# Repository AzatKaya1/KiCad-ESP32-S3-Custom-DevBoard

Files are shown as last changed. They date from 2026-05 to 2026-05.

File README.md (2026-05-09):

<div align="center">

# ⚡ ESP32-S3 Custom Development Board

</div>
<div align="center">

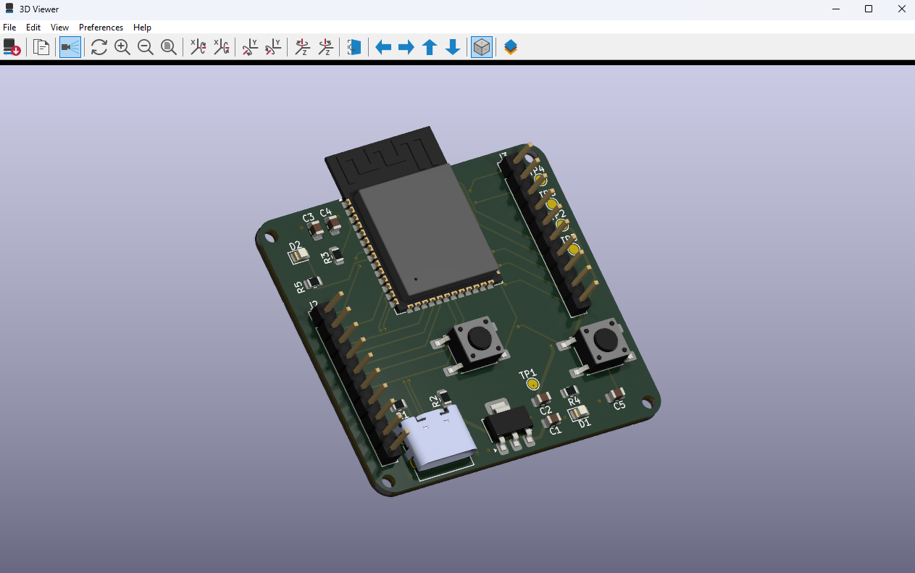
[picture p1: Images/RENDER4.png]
ESP32-S3 Custom DevBoard 3D Render


<br/>

**A production-grade, 4-layer PCB development board built around the ESP32-S3-WROOM-1 module.**  
Designed for signal integrity, RF performance, and professional-grade hardware standards.

<br/>



[]()

[]()

</div>

## 📋 Table of Contents

- [Overview](#-overview)
- [Key Features](#-key-features)
- [Technical Specifications](#-technical-specifications)
- [Advanced Hardware Design](#-advanced-hardware-design)
- [PCB Layer Stackup](#-pcb-layer-stackup)
- [Pinout & Peripherals](#-pinout--peripherals)
- [Repository Structure](#-repository-structure)
- [Manufacturing](#-manufacturing)

## 🔍 Overview

This project is an advanced, **production-ready development board** based on the **ESP32-S3-WROOM-1** module. It was designed with a focus on:

- ✅ **Signal Integrity** — Controlled impedance traces, optimized return paths
- ✅ **Power Stability** — Low-noise LDO regulation with proper decoupling
- ✅ **RF Performance** — Dedicated keep-out zone under the module antenna
- ✅ **Professional Standards** — 4-layer stackup, differential pair routing

This board is suitable for makers, engineers, and students who want a reliable ESP32-S3 platform for IoT, wireless communication, sensor integration, or embedded systems development.

## ✨ Key Features

| Feature | Detail |
|---|---|
| 🧠 MCU | ESP32-S3-WROOM-1 — Dual-core Xtensa LX7, Wi-Fi 4 & BLE 5.0 |
| ⚡ USB | Native USB-C for programming and power |
| 🔋 Power | 5V input → 3.3V via AMS1117-3.3 LDO |
| 📡 RF | Keep-out zone for optimized antenna performance |
| 📐 PCB | 4-layer stackup for reduced EMI |
| 🔌 Headers | UART, I2C, SPI — fully broken out |
| 📊 ADC | 2× dedicated analog input channels |
| 🔴 LEDs | Power LED (D1) + User-programmable LED (D2) |
| 🔘 Buttons | RESET (EN) + BOOT (GPIO0) |
| 🧪 Test Points | 5V, 3.3V, GND, TX, RX (TP1–TP5) |

## 🛠 Technical Specifications

| Parameter | Value |
|---|---|
| Microcontroller | ESP32-S3-WROOM-1 |
| CPU | Dual-core Xtensa LX7 @ up to 240 MHz |
| Wireless | Wi-Fi 802.11 b/g/n (2.4 GHz) + BLE 5.0 |
| Flash | Built-in (varies by module variant) |
| Input Voltage | 5V DC via USB-C |
| Operating Voltage | 3.3V (regulated via AMS1117-3.3) |
| PCB Layers | 4 (Signal / GND / Power / Signal) |
| PCB Tool | KiCad 9.0 |
| USB Interface | Native USB (D+/D- differential pair) |
| Programming | USB-C (native), UART via test points |

## 🔬 Advanced Hardware Design

### 1️⃣ 4-Layer PCB & Signal Integrity

The board uses a **4-layer stackup** to deliver superior electrical performance.

By using dedicated internal planes for **GND** and **3.3V**, electromagnetic interference (EMI) is significantly reduced, and power distribution is stabilized across the entire board.

### 2️⃣ Differential Pair Routing (USB D+/D-)

The USB-C data lines are routed as **90-ohm controlled impedance differential pairs**:

- Matched trace lengths for minimal skew
- Consistent spacing to maintain target impedance
- Prevents signal reflection and ensures error-free high-speed data transmission

### 3️⃣ RF Keep-Out Zone

A dedicated **RF Keep-Out Zone** is defined beneath the ESP32-S3-WROOM-1 antenna region:

- No copper, traces, or components on **any layer** in this region
- Maximizes Wi-Fi and Bluetooth range
- Minimizes signal attenuation and multipath interference

### 4️⃣ Power Design — AMS1117-3.3 LDO

The **AMS1117-3.3** was chosen for its:

- Low dropout voltage (~1.2V typical)
- 800mA output current capability
- Excellent noise performance for RF applications
- Wide availability and low cost for prototyping

> ⚠️ **Note:** For battery-powered or low-power designs, consider a more efficient LDO (e.g., MIC5219 or TPS7A20).

### 5️⃣ Decoupling & Bypass Capacitors

- 100nF ceramic capacitors placed close to each power pin of the ESP32-S3 module
- Bulk capacitance at the LDO output for transient response
- Ferrite bead filtering on power input

## 📐 PCB Layer Stackup

| Layer | Type | Description |
|---|---|---|
| Layer 1 (Top) | Signal | Components, USB, buttons, LEDs |
| Layer 2 | GND Plane | Solid ground pour — EMI shield & return path |
| Layer 3 | Power Plane | Solid 3.3V pour — stable power delivery |
| Layer 4 (Bottom) | Signal | Additional routing |

## 🔌 Pinout & Peripherals

| Header | Signals |
|---|---|
| UART | TX, RX, GND, 3.3V |
| I2C | SDA, SCL, GND, 3.3V |
| SPI | MOSI, MISO, SCK, CS, GND, 3.3V |
| ADC | ADC_CH1, ADC_CH2, GND |
| GPIO | Spare GPIO pins for custom expansion |
| Test Points | TP1 = 5V · TP2 = 3.3V · TP3 = GND · TP4 = TX · TP5 = RX |

## 📂 Repository Structure

| Folder / File | Description |
|---|---|
| `Hardware/` | KiCad 9.0 project files (`.kicad_pcb`, `.kicad_sch`, `.kicad_pro`) |
| `Manufacturing/` | Production-ready Gerber, Drill, and POS files |
| `Images/` | High-quality 3D renders |
| `.gitignore` | Git ignore rules |
| `LICENSE` | MIT License |
| `README.md` | This file |

## 🏭 Manufacturing

The `/Manufacturing` folder contains all files needed for PCB fabrication, compatible with major manufacturers:

| Service | Notes |
|---|---|
| [JLCPCB](https://jlcpcb.com) | Recommended — affordable 4-layer PCBs |
| [PCBWay](https://www.pcbway.com) | Good quality, various finish options |
| [OSH Park](https://oshpark.com) | US-based, ENIG finish standard |

**Recommended fab settings:**

| Parameter | Value |
|---|---|
| Layers | 4 |
| PCB Color | Black (recommended) |
| Surface Finish | HASL or ENIG |
| Board Thickness | 1.6mm |
| Copper Weight | 1oz outer / 0.5oz inner |
| Min Trace/Space | 0.15mm |
| Min Hole Size | 0.3mm |

---

<div align="center">

**Designed with  by [Azat KAYA](https://www.linkedin.com/in/azatkaya1/)**



*If this project helped you, consider giving it a ⭐ on GitHub!*

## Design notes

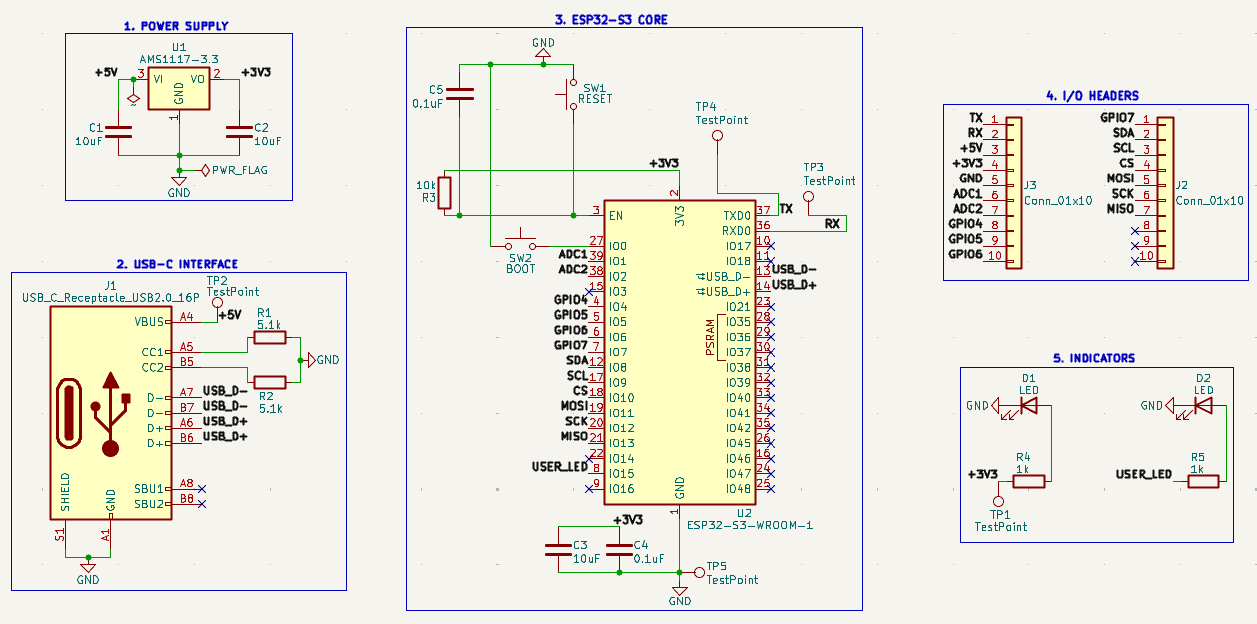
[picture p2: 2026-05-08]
Images/CIRCUIT_SCHEMATIC.png

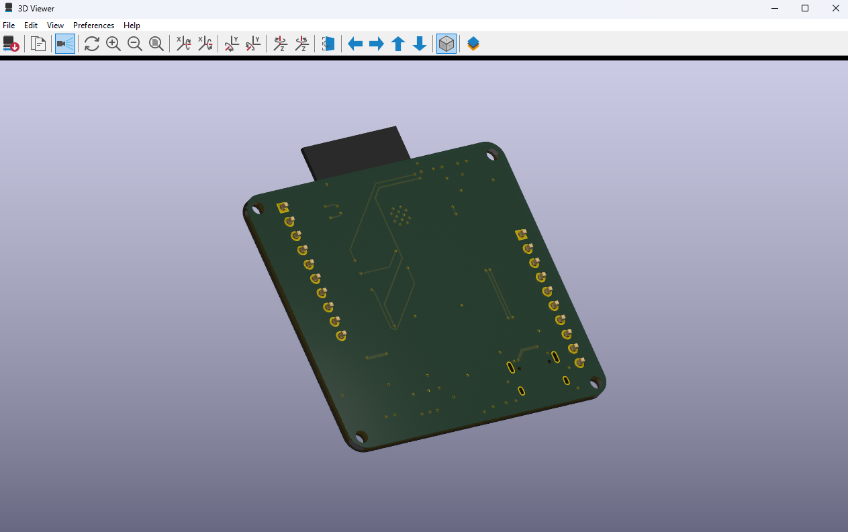
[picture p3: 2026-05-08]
Images/RENDER5.png

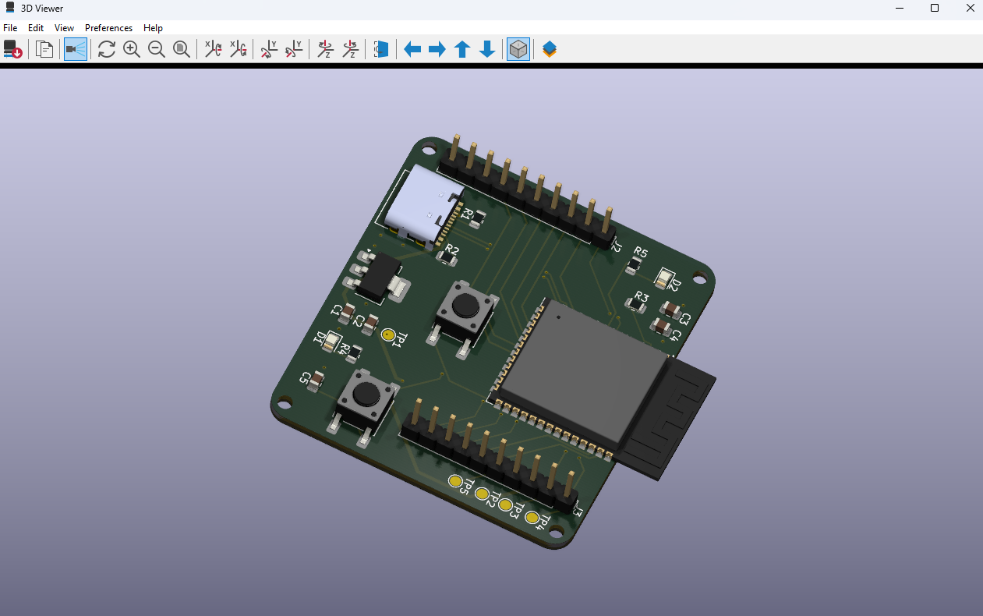
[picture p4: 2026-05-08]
Images/RENDER6.png

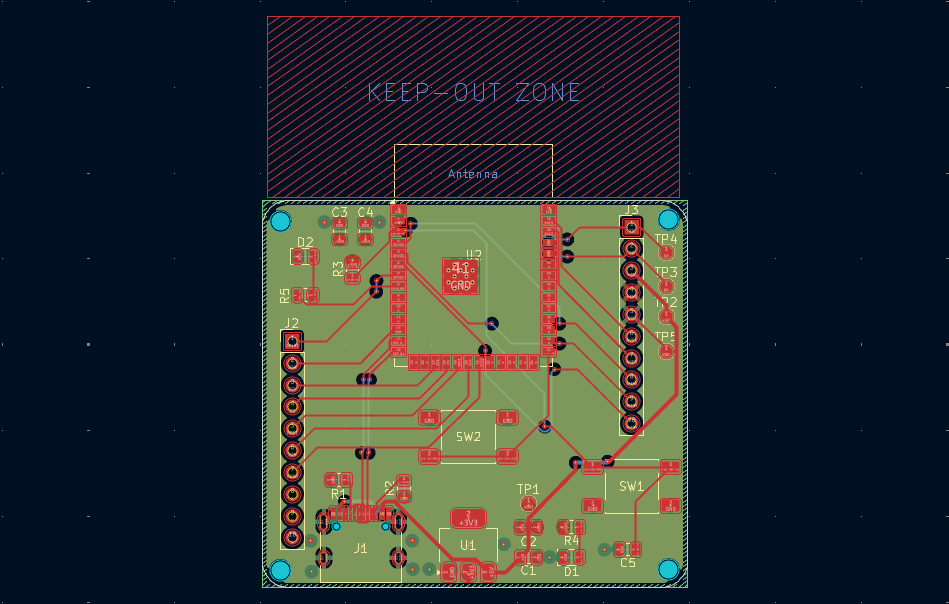
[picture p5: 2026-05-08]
Images/PCB.png

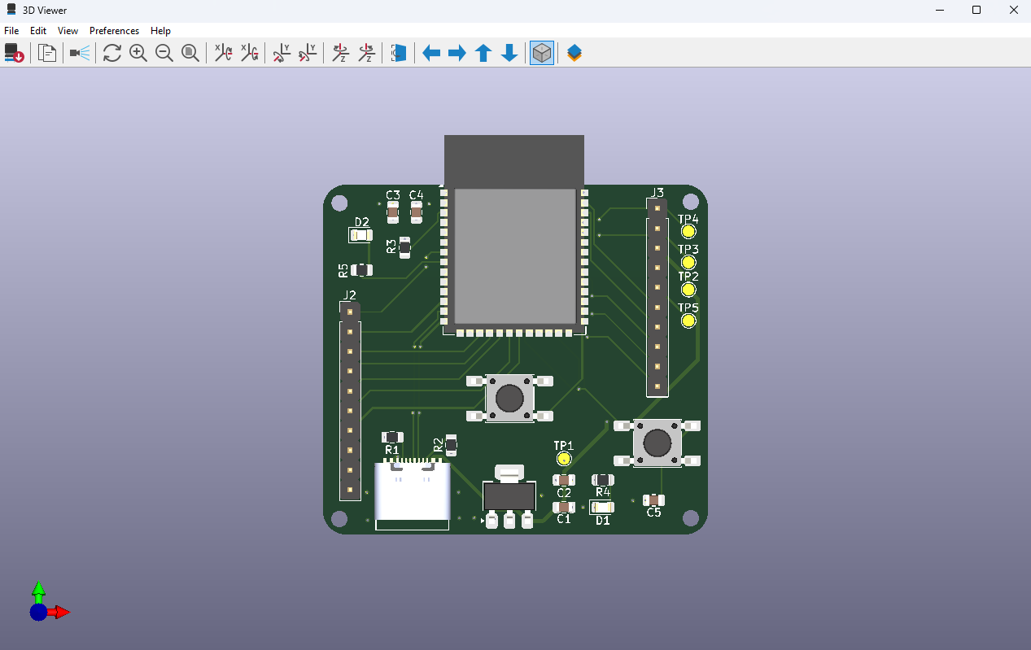
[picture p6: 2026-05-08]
Images/RENDER1.png

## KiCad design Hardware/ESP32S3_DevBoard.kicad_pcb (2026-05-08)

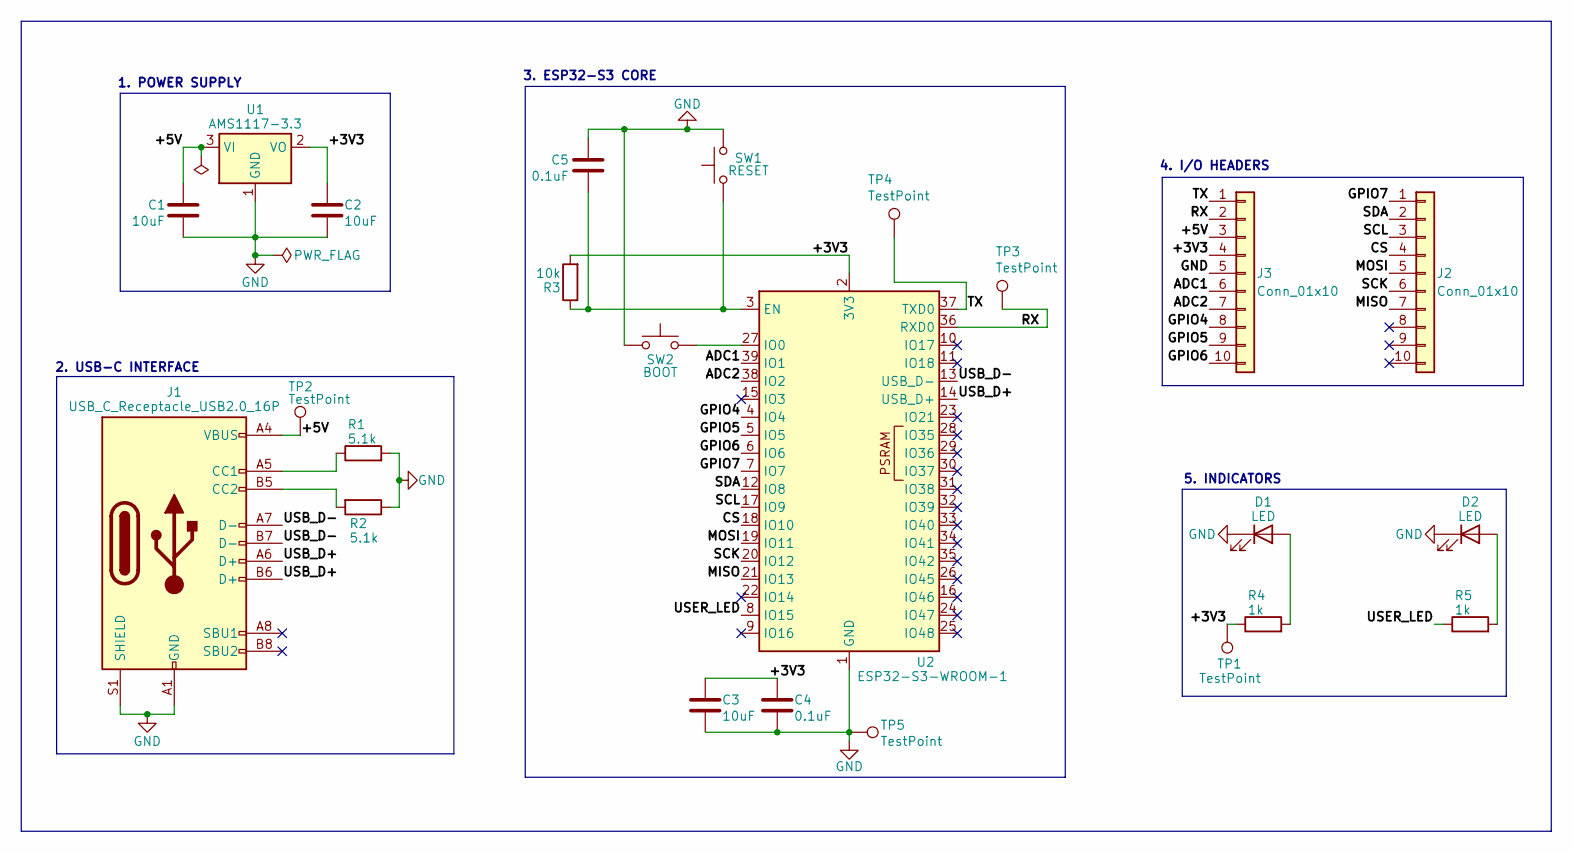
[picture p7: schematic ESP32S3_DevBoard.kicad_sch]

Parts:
C1, C2, C3: 10uF; C_0805_2012Metric
C4, C5: 0.1uF; C_0805_2012Metric
D1, D2: LED; LED_0805_2012Metric
J1: USB_C_Receptacle_USB2.0_16P; USB_C_Receptacle_HRO_TYPE-C-31-M-12
J2, J3: Conn_01x10; PinHeader_1x10_P2.54mm_Vertical
R1, R2: 5.1k; R_0805_2012Metric
R3: 10k; R_0805_2012Metric
R4, R5: 1k; R_0805_2012Metric
SW1: RESET; SW_Push_1P1T_NO_E-Switch_TL3301NxxxxxG
SW2: BOOT; SW_Push_1P1T_NO_E-Switch_TL3301NxxxxxG
TP1, TP2, TP3, TP4, TP5: TestPoint; TestPoint_Pad_D1.5mm
U1: AMS1117-3.3; SOT-223-3_TabPin2
U2: ESP32-S3-WROOM-1

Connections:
/+3V3: C2.1, C3.1, C4.1, J3.4, R3.2, R4.1, TP1.1, U1.2 (VO), U2.2 (3V3)
/+5V: C1.1, J1.A4 (VBUS), J1.A9 (VBUS), J1.B4 (VBUS), J1.B9 (VBUS), J3.3, TP2.1, U1.3 (VI)
/ADC1: J3.6, U2.39 (IO1)
/ADC2: J3.7, U2.38 (IO2)
/CS: J2.4, U2.18 (IO10)
/GPIO4: J3.8, U2.4 (IO4)
/GPIO5: J3.9, U2.5 (IO5)
/GPIO6: J3.10, U2.6 (IO6)
/GPIO7: J2.1, U2.7 (IO7)
/MISO: J2.7, U2.21 (IO13)
/MOSI: J2.5, U2.19 (IO11)
/RX: J3.2, TP3.1, U2.36 (RXD0)
/SCK: J2.6, U2.20 (IO12)
/SCL: J2.3, U2.17 (IO9)
/SDA: J2.2, U2.12 (IO8)
/TX: J3.1, TP4.1, U2.37 (TXD0)
/USB_D+: J1.A6 (D+), J1.B6 (D+), U2.14 (USB_D+)
/USB_D-: J1.A7 (D-), J1.B7 (D-), U2.13 (USB_D-)
/USER_LED: R5.1, U2.8 (IO15)
GND: C1.2, C2.2, C3.2, C4.2, C5.1, D1.1 (K), D2.1 (K), J1.A1 (GND), J1.A12 (GND), J1.B1 (GND), J1.B12 (GND), J1.S1 (SHIELD), J3.5, R1.2, R2.1, SW1.2, SW2.1, TP5.1, U1.1 (GND), U2.1 (GND), U2.40 (GND), U2.41 (GND)
unnamed: D1.2 (A), R4.2
unnamed: D2.2 (A), R5.2
unnamed: J1.A5 (CC1), R1.1
unnamed: J1.B5 (CC2), R2.2
unnamed: C5.2, R3.1, SW1.1, U2.3 (EN)
unnamed: SW2.2, U2.27 (IO0)

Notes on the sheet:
3. ESP32-S3 CORE
2. USB-C INTERFACE
5. INDICATORS
1. POWER SUPPLY
4. I/O HEADERS

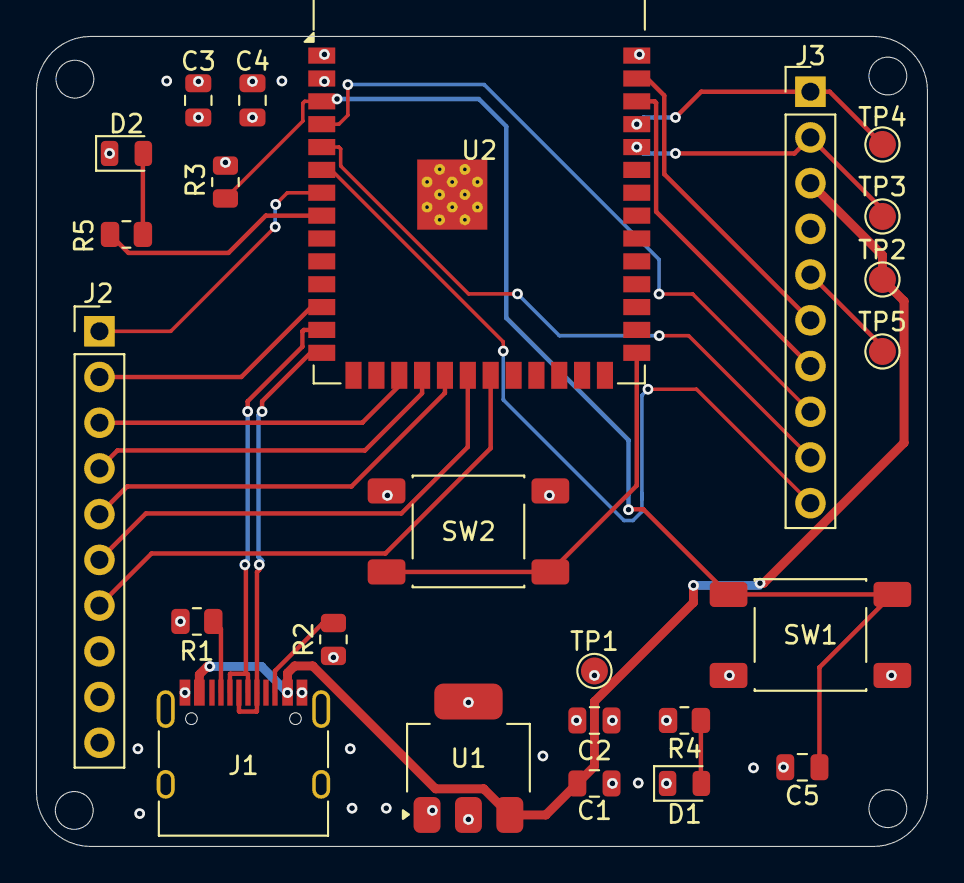
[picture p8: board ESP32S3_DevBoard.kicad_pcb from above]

Board: 4 copper layers, 49.5 x 45.0 mm, 24 parts (0 on the bottom side), 26 nets.
